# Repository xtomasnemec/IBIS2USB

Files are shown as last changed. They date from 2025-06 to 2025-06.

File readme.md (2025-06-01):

# IBIS to USB Converter

This project is a hardware solution for communicating with miscelaneous IBIS devices (BUSE BS210 etc.)

## Features

- Converts IBIS protocol to USB (virtual COM port)
- Mini USB
- Open hardware design (schematics and PCB in KiCad)

## Getting Started

1. Open the schematic and PCB files in KiCad.
2. Manufacture the PCB and assemble the components as specified.
3. Connect the IBIS and USB.
4. Use PuTTY to comunicate (1200 bit/s, 7 bits, even parity, 2 stop bits) or IBIS-Wagenbus Utility

## License

This project is open-source. See the LICENSE file for details.

## Credits

Developed by xtomasnemec.
Original IBIS to RS232 converter [here](https://jachyhm.cz/ois/Schemata/IBIS-COM_kompletni_schema.jpg).

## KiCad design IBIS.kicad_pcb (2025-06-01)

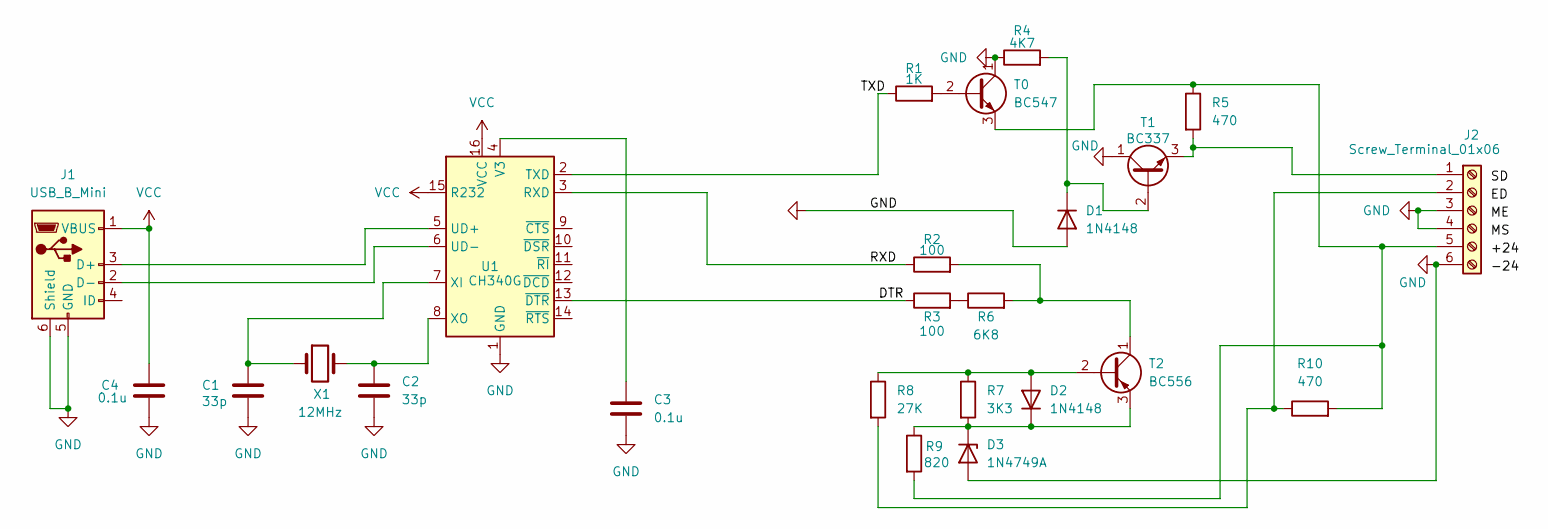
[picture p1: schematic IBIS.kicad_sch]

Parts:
C1, C2: 33p; C_Disc_D7.5mm_W5.0mm_P5.00mm
C3, C4: 0.1u; C_Disc_D7.5mm_W5.0mm_P5.00mm
D1, D2: 1N4148; D_DO-35_SOD27_P10.16mm_Horizontal
D3: 1N4749A; D_DO-41_SOD81_P10.16mm_Horizontal
J1: USB_B_Mini; USB_Mini-B_Wuerth_65100516121_Horizontal
J2: Screw_Terminal_01x06; TerminalBlock_WAGO_233-506_2x06_P2.54mm
R1: 1K; R_Axial_DIN0207_L6.3mm_D2.5mm_P10.16mm_Horizontal
R2, R3: 100; R_Axial_DIN0207_L6.3mm_D2.5mm_P10.16mm_Horizontal
R4: 4K7; R_Axial_DIN0207_L6.3mm_D2.5mm_P10.16mm_Horizontal
R5, R10: 470; R_Axial_DIN0207_L6.3mm_D2.5mm_P10.16mm_Horizontal
R6: 6K8; R_Axial_DIN0207_L6.3mm_D2.5mm_P10.16mm_Horizontal
R7: 3K3; R_Axial_DIN0207_L6.3mm_D2.5mm_P10.16mm_Horizontal
R8: 27K; R_Axial_DIN0207_L6.3mm_D2.5mm_P10.16mm_Horizontal
R9: 820; R_Axial_DIN0207_L6.3mm_D2.5mm_P10.16mm_Horizontal
T0: BC547; TO-92_Inline
T1: BC337; TO-92_Inline
T2: BC556; TO-92_Inline
U1: CH340G; SOIC-16_3.9x9.9mm_P1.27mm
X1: 12MHz; Crystal_HC49-4H_Vertical

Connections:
/DTR: R3.1, U1.13 (~DTR)
/RXD: R2.1, U1.3 (RXD)
GND: C1.2, C2.2, C3.2, C4.2, D1.2 (A), D3.2 (A), J1.5 (GND), J1.6 (Shield), J2.3, J2.4, J2.6, R4.1, T0.1 (C), T1.1 (C), U1.1 (GND)
unnamed: D1.1 (K), R4.2, T1.2 (B)
unnamed: D2.2 (A), R7.1, R8.1, T2.2 (B)
unnamed: D2.1 (K), D3.1 (K), R7.2, R9.1, T2.3 (E)
unnamed: J1.3 (D+), U1.5 (UD+)
unnamed: J1.2 (D-), U1.6 (UD-)
unnamed: J2.1, R5.2, T1.3 (E)
unnamed: J2.2, R8.2, R10.1
unnamed: J2.5, R5.1, R9.2, R10.2, T0.3 (E)
unnamed: R3.2, R6.1
unnamed: R1.2, T0.2 (B)
unnamed: R2.2, R6.2, T2.1 (C)
unnamed: R1.1, U1.2 (TXD)
unnamed: C3.1, U1.4 (V3)
unnamed: C1.1, U1.7 (XI), X1.1
unnamed: C2.1, U1.8 (XO), X1.2
VCC: C4.1, J1.1 (VBUS), U1.15 (R232), U1.16 (VCC)

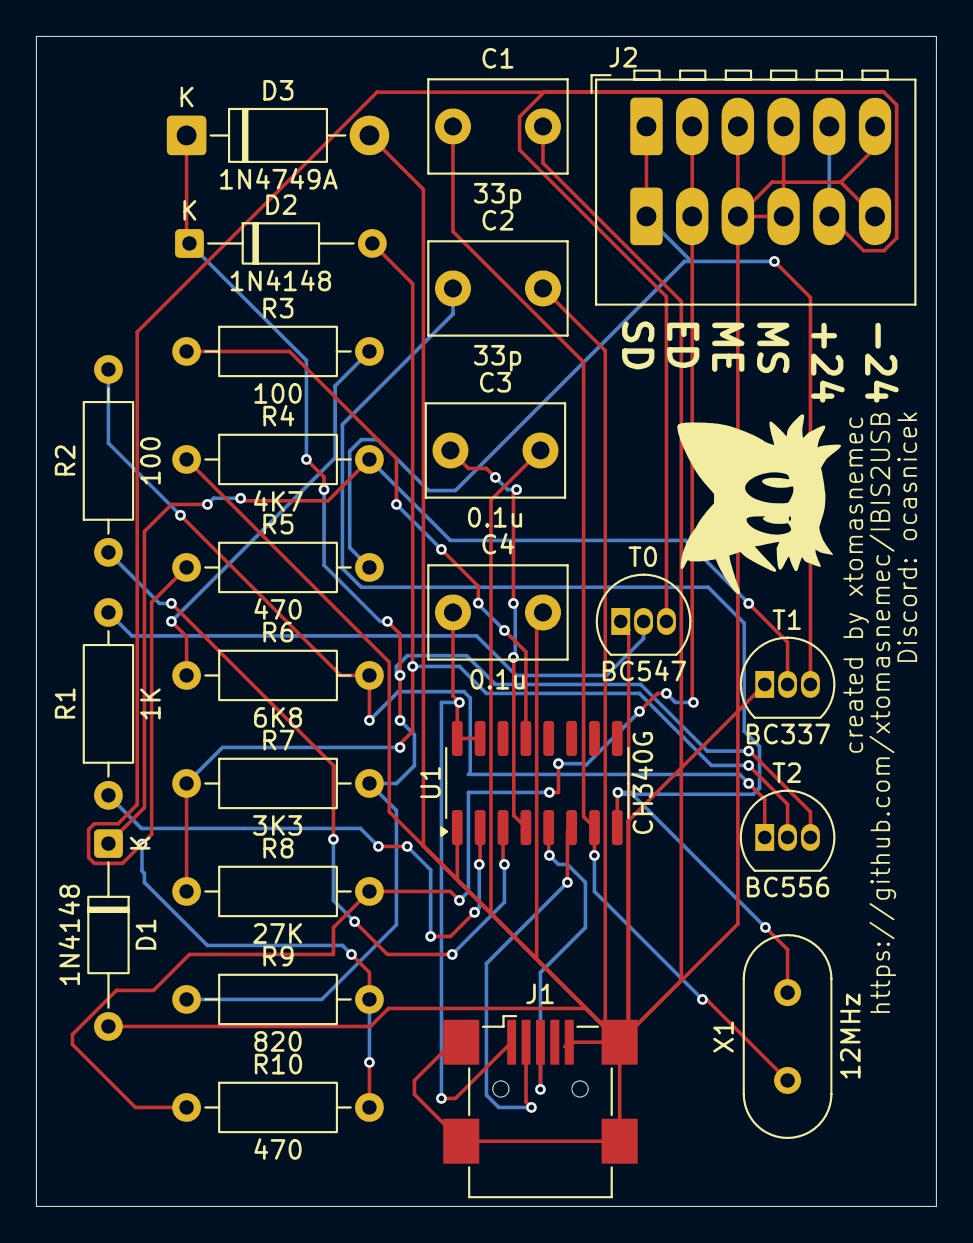
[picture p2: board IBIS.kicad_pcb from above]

Board: 2 copper layers, 50.0 x 65.0 mm, 24 parts (0 on the bottom side), 19 nets.

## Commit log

2025-06-01 Full schematic only
    [IBIS.kicad_pcb, IBIS.kicad_sch]
2025-06-01 PCB design
    [IBIS.kicad_pcb, IBIS.kicad_sch]
